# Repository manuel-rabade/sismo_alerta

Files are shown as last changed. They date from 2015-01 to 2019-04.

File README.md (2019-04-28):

Sismo Alerta
============

Receptor libre de la señal pública del [Sistema de Alerta Sísmica
Mexicano](http://www.cires.org.mx/sasmex_es.php).

Sismo Alerta emite un fuerte sonido y parpadea sus leds en caso de
recibir la alerta sísmica. Incluye batería de respaldo para no depender
de la energía de la red eléctrica.

Funcionamiento
--------------

Sismo Alerta es posible gracias a la señal pública del Sistema de Alerta
Sísmica Mexicano operado por el [Centro de Instrumentación y Registro
Sísmico](http://www.cires.org.mx/).

La señal del Sistema de Alerta Sísmica Mexicano es de tipo
[VHF](http://en.wikipedia.org/wiki/Very_high_frequency) en los canales
de [Weather Radio](http://en.wikipedia.org/wiki/Weather_radio) y utiliza
una versión modificiada del [protocolo
SAME](http://en.wikipedia.org/wiki/Specific_Area_Message_Encoding) para
transmitir alertas sobre distintos riesgos.

Sismo Alerta sintoniza y decodifica esta señal gracias al chip
[Si4707](http://www.silabs.com/products/audio/fm-am-receiver/pages/si4707.aspx)
que junto a una placa [Arduino](http://arduino.cc) dispara la alerta
sísmica de acuerdo al mensaje recibido.

Advertencia
-----------

Construye, utiliza y comparte Sismo Alerta bajo tu propio riesgo.

Sismo Alerta un proyecto experimental ejecutado por medio de [Ingeniería
inversa](https://es.wikipedia.org/wiki/Ingenier%C3%ADa_inversa) del
Sistema de Alerta Sísmica Mexicanos, además no cuenta con ninguna
certificación o permiso del Centro de Instrumentación y Registro
Sísmico, Gobierno de la Ciudad de México o Gobierno Federal.

Prototipo
---------

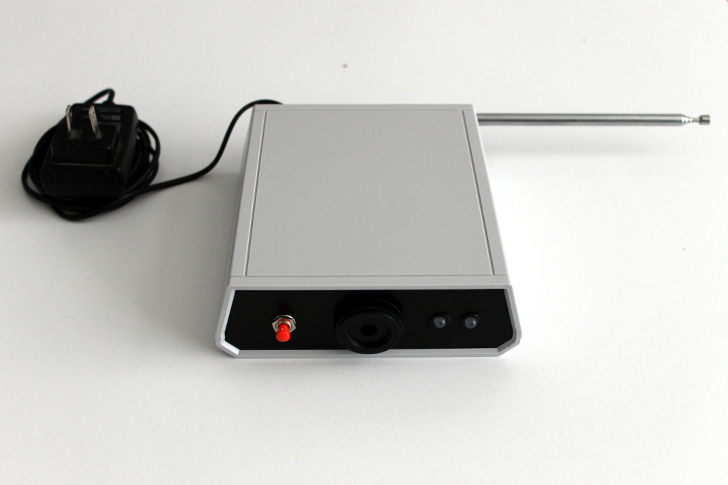
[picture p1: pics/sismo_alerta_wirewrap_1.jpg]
Wirewrap 1 (https://flic.kr/p/qupofe)


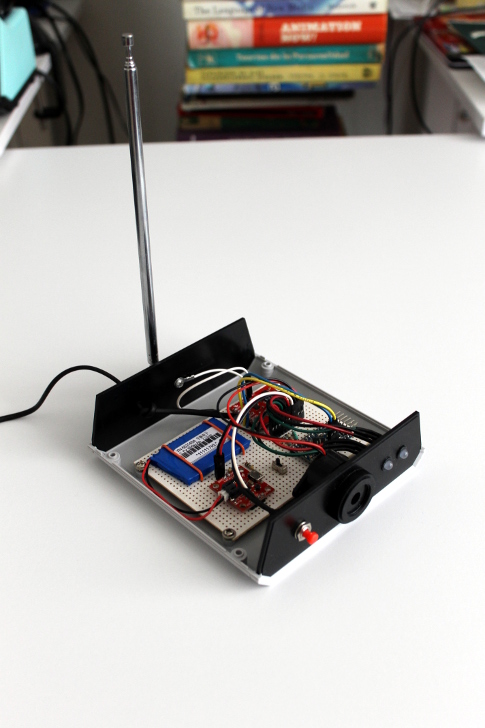
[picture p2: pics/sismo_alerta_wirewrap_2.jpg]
Wirewrap 2 (https://flic.kr/p/pPRnoG)


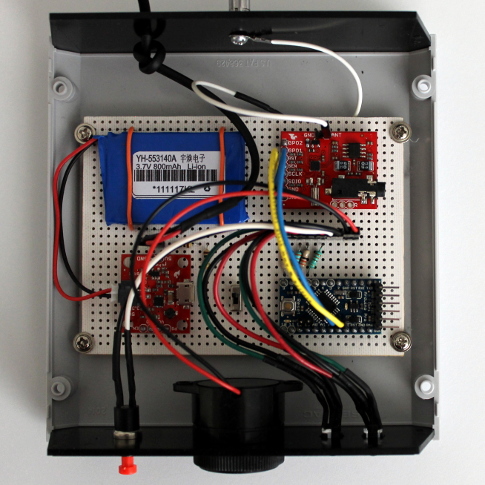
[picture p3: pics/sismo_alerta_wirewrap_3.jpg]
Wirewrap 3 (https://flic.kr/p/qwKxXX)


Kit
---

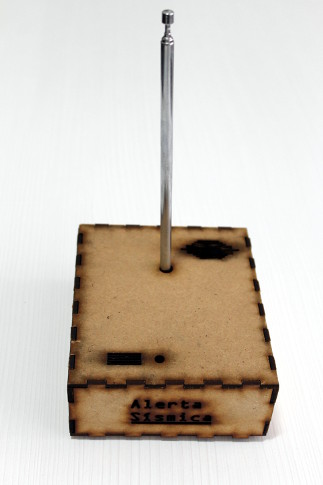
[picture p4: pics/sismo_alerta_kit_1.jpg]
Kit 1 (https://flic.kr/p/s8GZrR)


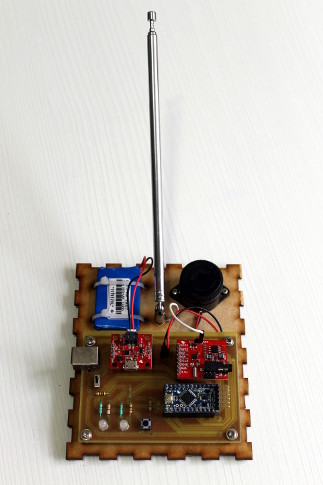
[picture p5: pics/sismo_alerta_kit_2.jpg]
Kit 2 (https://flic.kr/p/rvefon)


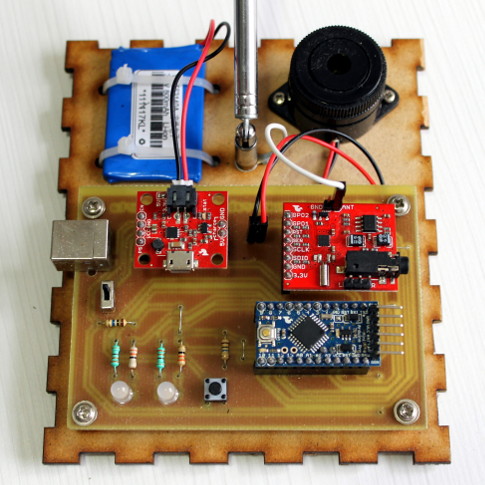
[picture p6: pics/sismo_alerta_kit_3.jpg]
Kit 3 (https://flic.kr/p/sarKxh)


Operación
---------

La interacción con el usuario es por medio de:

- Led bicolor (rojo y verde) marcado como _energía_.
- Led bicolor (rojo y verde) marcado como _señal_.
- Zumbador.
- Botón de usuario.

Al encender Sismo Alerta realiza una autoprueba que consiste en:

1. Encender ambos leds en color verde y activar el zumbador
2. Encender ambos leds en color rojo y desactivar el zumbador
3. Apagar ambos leds

Si después de la autoprueba se enciende el led de energía en color rojo
existe un problema interno.

Después de la autoprueba Sismo Alerta buscara el canal con mejor calidad
para monitorear la alerta sísmica. En caso de no encontrar un canal se
encenderá el led de señal en color rojo.

En caso de sintonizar un canal con éxito el led de señal encenderá
intermitentemente en color verde. Cuando Sismo Alerta reciba la prueba
periódica del Sistema de Alerta Sísmica el led de señal dejara de
parpadear y quedara encendido en color verde. El mensaje de prueba se
transmite cada 3 horas a partir de las 2:45.

En caso de recibir un mensaje de alerta sísmica ambos leds encenderán
intermitentemente en color rojo y el zumbador se activara. La duración
de la alerta es de 60 segundos.

Para probar Sismo Alerta basta con presionar el botón de usuario durante
al menos 3 segundos y se activara la alerta sísmica durante 10 segundos.

En resumen, los leds indican:

Led|Color|Significado
---|-----|-----------
Energía y Señal|Intermitente Rojo|Alerta sísmica
Señal|Apagado|Sintonizando canal por primera vez
Señal|Intermitente Verde|Canal sintonizado, esperando prueba periódica
Señal|Verde|Canal sintonizado y prueba periódica vigente
Señal|Rojo|No se pudo sintonizar un canal
Energía|Apagado|Apagada, batería de respaldo agotada
Energía|Verde|Alimentada por la red eléctrica
Energía|Intermitente Verde|Alimentada por la batería de respaldo
Energía|Rojo|Problema interno de hardware

Hardware
--------

### Lista de partes

Cantidad | Descripción
-------- | -----------
1 | [Arduino Pro Mini 3.3 V @ 8 Mhz](http://arduino.cc/en/Main/ArduinoBoardProMini)
1 | [Power Cell: LiPo Charger/Booster](https://www.sparkfun.com/products/11231) **
1 | [Si4707 Weather Band Receiver Breakout](https://www.sparkfun.com/products/11129)
1 | Batería Li-Ion 3.7 V @ 800 mAh conector JST **
2 | Led Bicolor 5 mm rojo/verde catodo común
2 | Resistencia 33 Ω 1/4 W
2 | Resistencia 330 Ω 1/4 W
2 | Resistencia 10M Ω 1/4 W
1 | Antena monopolo
1 | Zumbador
1 | Botón pulsador normalmente abierto
1 | Swtich 1 polo 2 tiros 2 posiciones **
1 | Conector USB tipo B hembra
1 | Convertidor AC a DC 5 V @ 500 mA conector USB tipo B macho

** Versión con batería de respaldo

#### Antena monopolo

Por la frecuencia de la señal pública del Sistema de Alerta Sísmico
Mexicano es muy fácil construir o adaptar una antena que nos permita
sintonizarla, hay dos opciones:

1. Tramo de 45 cm de cable.
2. Un elemento de una _antena de conejo_.

#### Importante

- Configurar la Power Cell a 3.3 V (cortar jumper 5V y soldar 3.3V).
- Configurar Si4707 Breakout para usar una antena externa (cortar jumper
  HP y soldar EXT).

### Esquema de conexiones

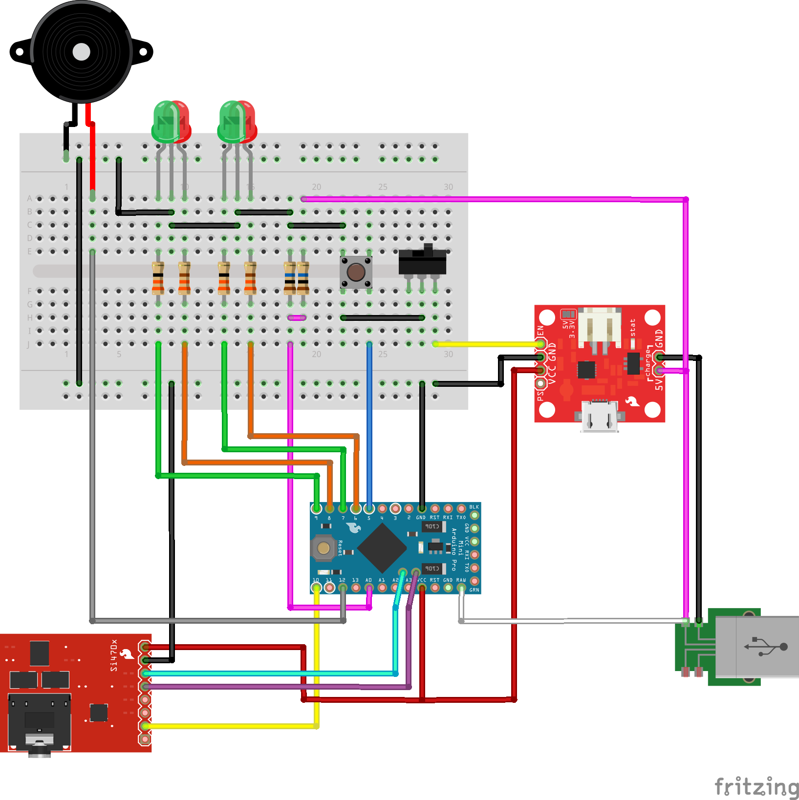
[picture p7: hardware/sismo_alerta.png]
Schematics


- La conexión blanca (abajo derecha) se debe hacer solo en caso de la
  versión sin batería de respaldo y Power Cell.

- No se muestra la antena que debe ir conectada al pin ANT de la Si4707
  Weather Band Receiver Breakout ni la batería que debe ir al conector
  JST de la Power Cell.

### PCB Kit

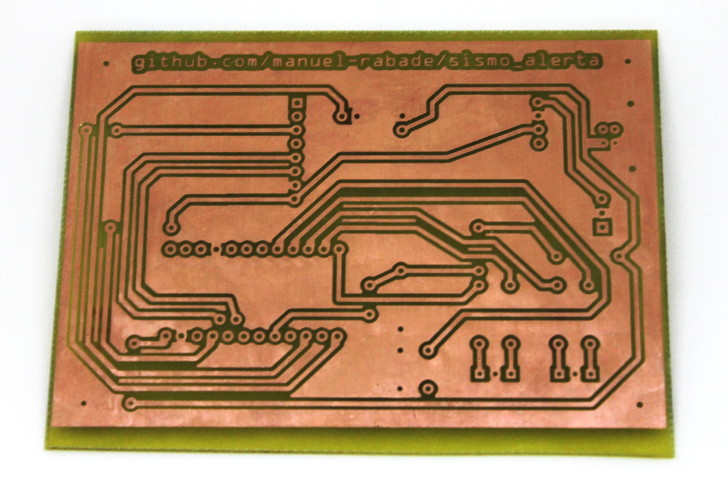
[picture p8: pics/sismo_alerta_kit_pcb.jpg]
Kit PCB (https://flic.kr/p/srSpnf)


- Pistas de cobre: [SVG](hardware/sismo_alerta_copper.svg), [2x2 SVG](hardware/sismo_alerta_copper_2x2.svg) o [2x2 PDF](hardware/sismo_alerta_copper_2x2.pdf)

- Máscara de soldadura: [SVG](hardware/sismo_alerta_mask.svg), [2x2 SVG](hardware/sismo_alerta_mask_2x2.svg) o [2x2 PDF](hardware/sismo_alerta_mask_2x2.pdf)

#### Componentes

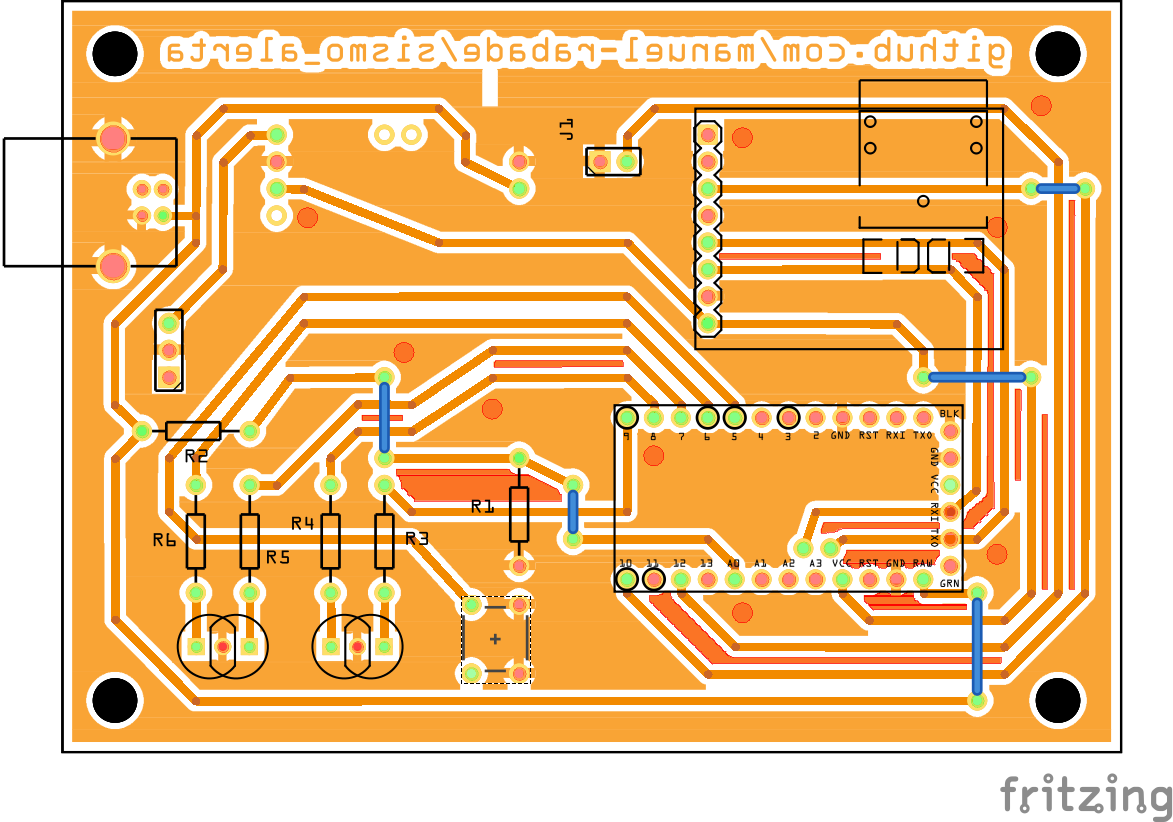
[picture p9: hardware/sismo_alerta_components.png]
Componentes PCB


Componente | Notas
---------- | -----
J1 | Puerto zumbador
R1, R2 | Resistencia 10M Ω 1/4 W
R3, R5 | Resistencia 33 Ω 1/4 W
R4, R6 | Resistencia 330 Ω 1/4 W
Jumper3 | (Esquina inferior derecha) Se debe omitir en la versión con batería de respaldo
S6 | Switch para apagar la versión con batería de respaldo en caso de almacenarla y así evitar se dañe la batería por perder toda la carga
Leds Bicolor | Comúnmente la terminal más larga corresponde al color rojo y esta va orientada hacía R4 o R6

### Gabinete Kit

- [SVG de la base para montaje](hardware/sismo_alerta_base.svg)
- Pendiente diseño del gabinete MDF

Firmware
--------

Para Arduino IDE 1.8.9 y requiere las siguientes bibliotecas:

- [Si4707 Weather Band Radio Receiver Library](https://github.com/manuel-rabade/Arduino-Si4707-Library)
- [TimerOne Library](https://github.com/PaulStoffregen/TimerOne)

La estructura de [SismoAlerta.ino](firmware/SismoAlerta/SismoAlerta.ino)
es:

- Una maquina de estados en el ciclo infinito del sketch encargada
  escaneo de canales y monitoreo de mensajes.
- Una interrupción periódica que monitorea el botón de usuario,
  actualiza los leds del dispositivo y activa el zumbador.

Los parámetros de operación del firmware se puede configurar en
[SismoAlerta.h](firmware/SismoAlerta/SismoAlerta.h).

En el puerto serial se registran los eventos de Sismo Alerta, por
ejemplo:

```
SETUP
SELFTEST
BEGIN
SCAN_START
SCAN_AVG,162400,9,0.00,0.00
SCAN_AVG,162425,9,0.00,0.00
SCAN_AVG,162450,9,0.00,0.00
SCAN_AVG,162475,9,0.00,0.00
SCAN_AVG,162500,9,2.00,7.56
SCAN_AVG,162525,9,0.00,0.00
SCAN_AVG,162550,9,5.00,8.78
SCAN_OK,162550
SNR_RSSI_AVG,162550,240,3.84,8.65
SNR_RSSI_AVG,162550,240,2.58,7.75
SNR_RSSI_AVG,162550,240,1.50,5.92
SAME_PRE_DET
SAME_HDR_DET
SAME_HDR_RDY,1
SAME_PRE_DET
SAME_HDR_DET
SAME_HDR_RDY,2
SAME_PRE_DET
SAME_HDR_DET
SAME_HDR_RDY,3
SAME,-CIV-RWT-000000+0300-1311431-XGDF/001-..,.
SAME_RWT
SAME_EOM_DET
SAME_PRE_DET
SAME_EOM_DET
SAME_PRE_DET
SAME_EOM_DET
SAME_PRE_DET
SAME_EOM_DET
SNR_RSSI_AVG,162550,240,1.97,6.38
SNR_RSSI_AVG,162550,240,2.72,8.13
```

Monitor
-------

Esta versión del Hardware utiliza un [Arduino
Yún](http://arduino.cc/en/Main/ArduinoBoardYun) para monitorear la
operación de Sismo Alerta.

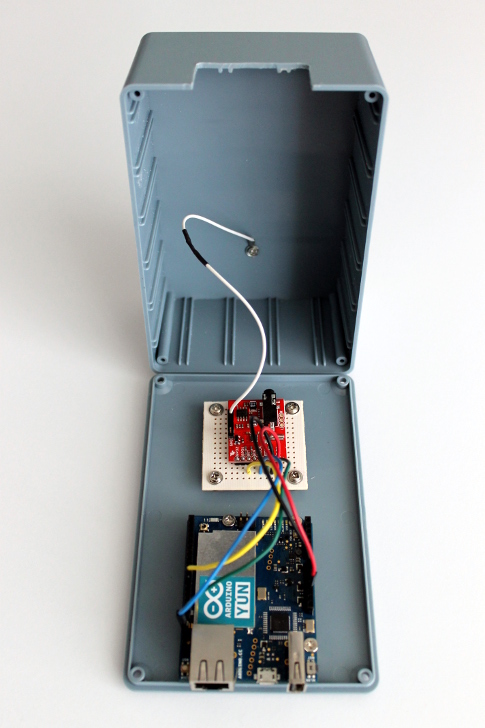
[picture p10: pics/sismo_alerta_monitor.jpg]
Monitor (https://flic.kr/p/qJyAiN)


#### Importante

Para que funcionen correctamente las opciones de la versión monitor se
debe descomentar la linea `reset-mcu` en `/etc/rc.local` del Linux
empotrado en el Arduino Yún. El objetivo es habilitar el reinicio del
microcontrolador después de terminar el arranque del Linux empotrado.

### Bitácora

Esta opción del Firmware guarda en archivos de texto cada evento de
Sismo Alerta.

El script [sismo_alerta_logger](software/logger/sismo_alerta_logger)
recibe los eventos de Sismo Alerta por medio de la consola virtual y los
guarda en carpetas y archivos de texto de acuerdo al año y día en que fueron
generados.

Para implementar la bitácora se debe:

1. Insertar una memoria SD previamente particionada y formateada en el
Arduino Yún. La memoria SD debe automontarse en `/mnt/sda1/` en el Linux
empotrado.

2. En el Linux empotrado del Arduino Yún se debe crear el directorio
`/mnt/sda/log` donde se guardaran las bitácoras de operación y copiar el
script [sismo_alerta_logger](software/logger/sismo_alerta_logger) en
`/root`.

3. En [SismoAlerta.h](firmware/SismoAlerta/SismoAlerta.h) activar la
opción `YUN_LOGGER`.

Un fragmento de bitácora del archivo `2015/0223.txt` seria:

```
[2015-02-23 13:38:00] SETUP
[2015-02-23 13:38:00] SELFTEST
[2015-02-23 13:39:02] BEGIN
[2015-02-23 13:39:03] SCAN_START
[2015-02-23 13:39:29] SCAN_AVG,162400,9,0.00,0.00
[2015-02-23 13:39:29] SCAN_AVG,162425,9,0.00,0.00
[2015-02-23 13:39:29] SCAN_AVG,162450,9,2.44,14.78
[2015-02-23 13:39:29] SCAN_AVG,162475,9,0.00,0.00
[2015-02-23 13:39:30] SCAN_AVG,162500,9,2.11,10.89
[2015-02-23 13:39:30] SCAN_AVG,162525,9,0.00,0.00
[2015-02-23 13:39:30] SCAN_AVG,162550,9,0.78,11.22
[2015-02-23 13:39:30] SCAN_OK,162450
[2015-02-23 13:59:33] SNR_RSSI_AVG,162450,240,2.49,16.12
[2015-02-23 14:19:35] SNR_RSSI_AVG,162450,240,1.38,15.40
[2015-02-23 14:39:37] SNR_RSSI_AVG,162450,240,1.23,15.21
[2015-02-23 14:45:02] SAME_PRE_DET
[2015-02-23 14:45:02] SAME_HDR_DET
[2015-02-23 14:45:03] SAME_HDR_RDY,1
[2015-02-23 14:45:05] SAME_PRE_DET
[2015-02-23 14:45:05] SAME_HDR_DET
[2015-02-23 14:45:06] SAME_HDR_RDY,2
[2015-02-23 14:45:07] SAME_PRE_DET
[2015-02-23 14:45:08] SAME_HDR_DET
[2015-02-23 14:45:08] SAME_HDR_RDY,3
[2015-02-23 14:45:09] SAME,-CIV-RWT-000000+0300-1311432-XGDF/003-D&@...
[2015-02-23 14:45:09] SAME_RWT
[2015-02-23 14:45:09] SAME_EOM_DET
[2015-02-23 14:45:10] SAME_PRE_DET
[2015-02-23 14:45:10] SAME_EOM_DET
[2015-02-23 14:45:12] SAME_PRE_DET
[2015-02-23 14:45:12] SAME_EOM_DET
[2015-02-23 14:45:14] SAME_PRE_DET
[2015-02-23 14:45:14] SAME_EOM_DET
[2015-02-23 14:59:39] SNR_RSSI_AVG,162450,240,2.14,10.37
[2015-02-23 15:19:41] SNR_RSSI_AVG,162450,240,1.82,11.26
[2015-02-23 15:39:43] SNR_RSSI_AVG,162450,240,2.27,11.83
```

### Repetidor Twitter

Esta opción del Firmware envía a un script web cada mensaje SAME
recibido. **El objetivo de esta opción no es transmitir la alerta
sísmica al público en general.**

El script [arduino.php](software/twitter/arduino.php) recibe los
mensajes SAME, los guarda en archivos de texto y los publica en Twitter
como [@SismoAlertaMX](https://twitter.com/sismoalertamx).

Para implementar el repetidor en twitter se debe:

1. Configurar en [config.php](software/twitter/config.php.sample) los
parámetros para guardar y consultar los mensajes SAME además de las
llaves secretas de Sismo Alerta y Twitter.

2. En [SismoAlerta.h](firmware/SismoAlerta/SismoAlerta.h) activar la
opción `YUN_TWITTER`.

3. En `yun_twitter.h` se debe configurar la URL del web service de Sismo
Alerta con su llave secreta (ver
[yun_twitter.h.example](firmware/SismoAlerta/yun_twitter.h.example)).

Autor
-----

Manuel Rábade <[manuel@rabade.net](mailto:manuel@rabade.net)>

Licencia
--------

Esta obra está bajo una [licencia de Creative Commons
Reconocimiento-CompartirIgual 4.0
Internacional](http://creativecommons.org/licenses/by-sa/4.0/).

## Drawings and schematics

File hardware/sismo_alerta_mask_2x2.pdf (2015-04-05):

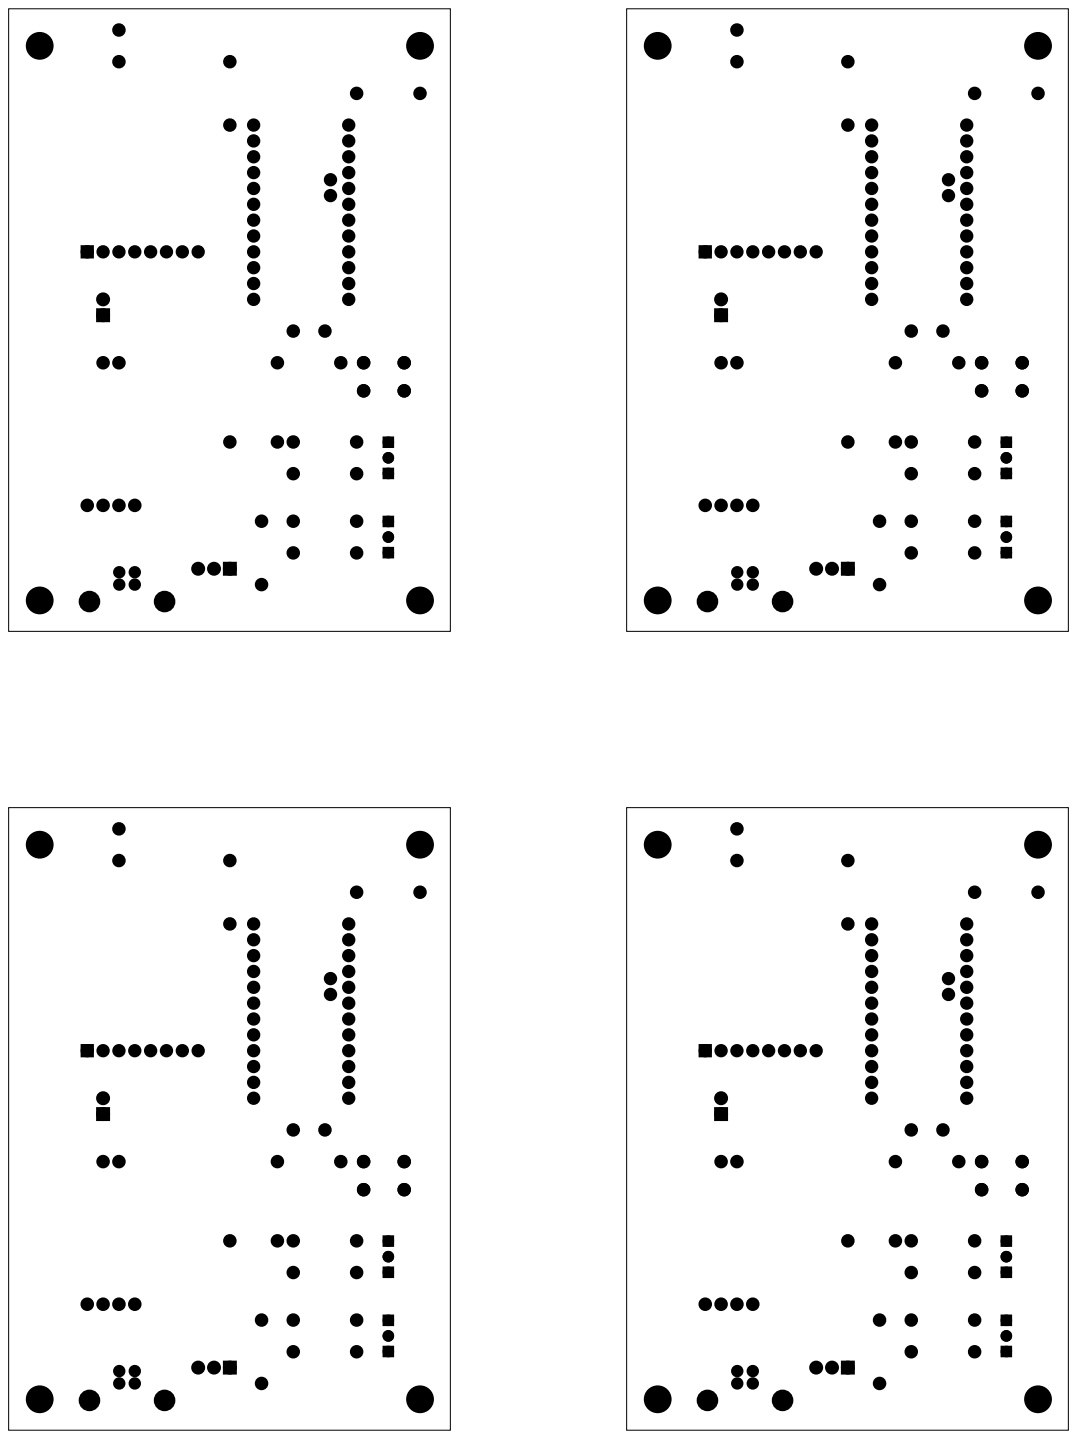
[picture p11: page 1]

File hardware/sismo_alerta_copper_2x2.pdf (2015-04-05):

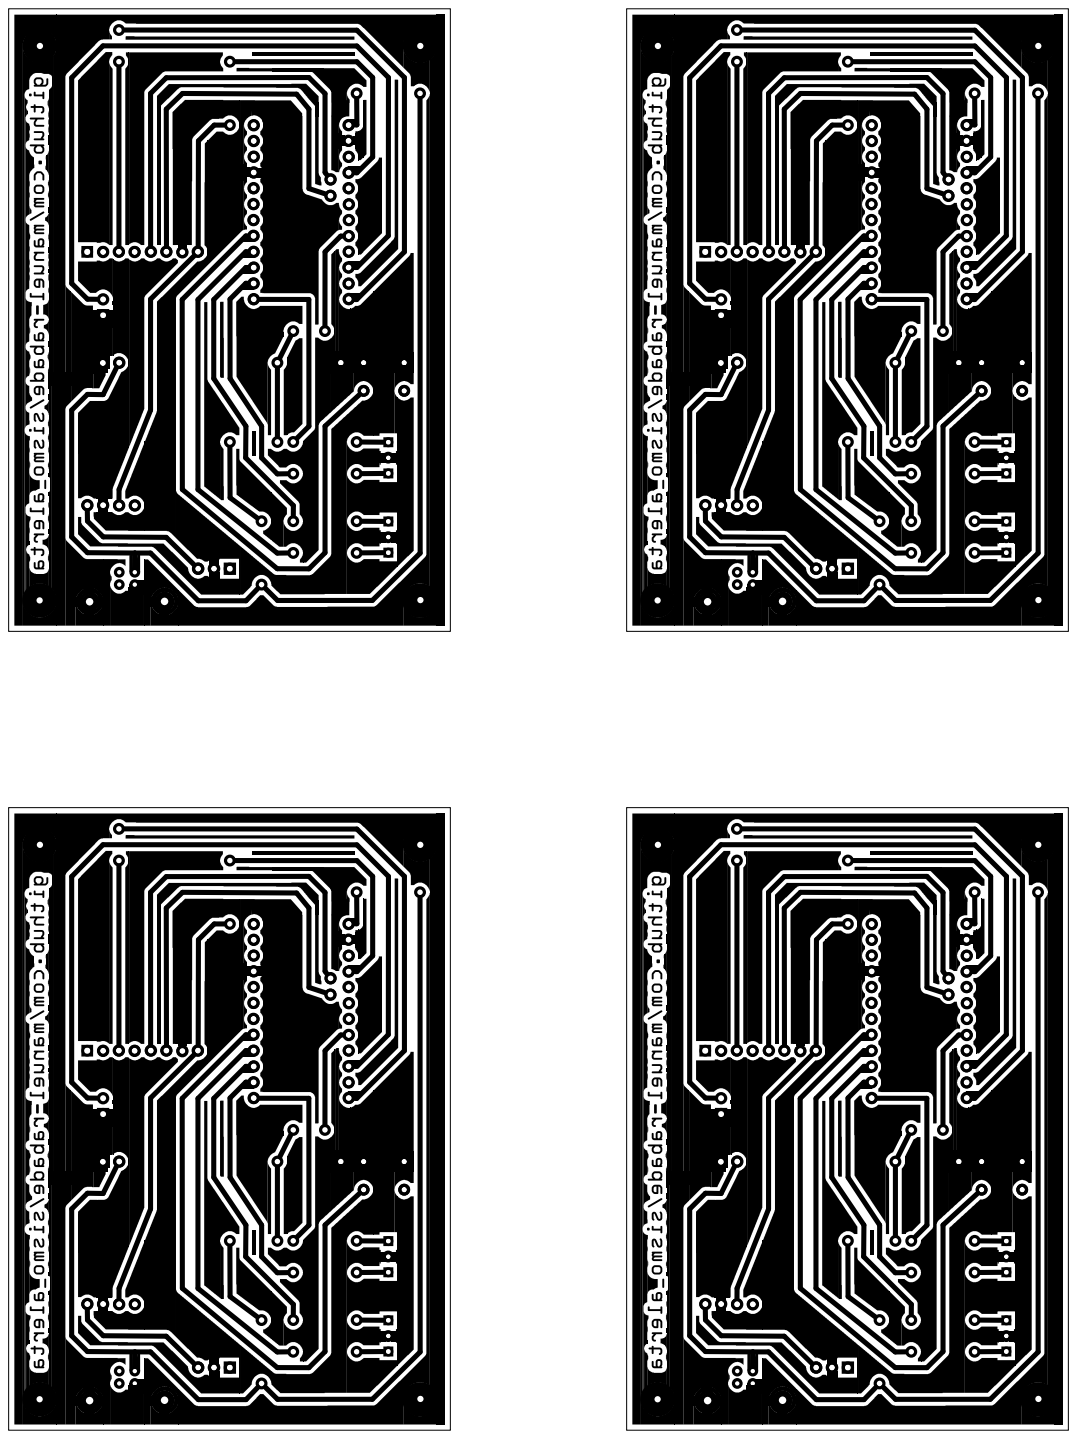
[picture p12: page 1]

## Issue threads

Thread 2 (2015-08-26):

Cambiar el voltaje del sistema de 3.3V a 5V

manuel-rabade, 2015-08-26:
Algunas Si4707 Weather Band Receiver Breakout (https://www.sparkfun.com/products/11129) no pueden establecer comunicación con el Arduino Pro Mini. Se necesita:

- Configurar Power Cell a 5V
- Agregar un regulador de voltaje de 3.3V para alimentar la Si4707 Breakout
- Ajustar conexiones de alimentación USB - PowerCell - Arduino Pro Mini - Si4707 Breakout
- Ajustar detección de energía externa en el firmware

La razón es que la Si47407 Breakout requiere alimentación de 3.3V pero esta diseñada para comunicarse a 5V (tienen un divisor de voltaje en SCLK y SDIO, ver https://cdn.sparkfun.com/datasheets/Wireless/General/SparkFun_Si4707_Breakout_v11.pdf).

Una solución temporal a este problema es eliminar los divisores de voltaje en SCLK y SDIO de la Si4707 Breakout (Quitar R3, R4, R5 y R6 y soldar jumpers en R3 y R4).

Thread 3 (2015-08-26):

Migrar esquemático y PCB de Fritzing

manuel-rabade, 2015-08-26:
- ¿El nuevo PCB debe ser de una cara (más practico para el DIY) o dos caras (apto para PCB Fab)?
- ¿Qué software de EDA es mejor que Fritzing? ¿Kicad? ¿Una solución en la nube como la de Altium o Upverter? Pros y contras.

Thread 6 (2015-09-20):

Mensaje en S.A.M.E.

sabas1080, 2015-09-20:
Hola, excelente trabajo
¿tendrás entre tus curiosidades uno(s) mensaje(s) completo(s) de SAME que me puedas pasar?

-CIV-RWT-000000+0300-1311432-XGDF/003-D&@...

saludos y gracias

manuel-rabade, 2015-11-16:
Hola,

Antes que nada muchas gracias por las felicitaciones y de verdad una disculpa por la demora.

Te comparto por acá ftp.rabade.net/tmp/sismo_alerta_logs-20150127-20150825.tar.gz los registros de operación del 26 de Enero al 28 de Agosto de la versión monitor de Sismo Alerta. En ellos puedes ver los mensajes SAME en crudo además de otras cosas como los reportes de calidad de recepción.

También por otra parte puedes dar click en los enlaces que acompañan a las publicaciones de https://twitter.com/sismoalertamx para ver el mensaje SAME en texto plano.

Saludos!

Closed 2015-11-16.

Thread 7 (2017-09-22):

¿Aún se encuentra activo el proyecto?

dsalcedo, 2017-09-22:

pixelead0, 2017-09-22:
Hola @dsalcedo al parecer el proyecto es funcional, al menos que sugieras alguna mejora.

manuel-rabade, 2017-09-23:
Mi última contribución al repo fue hace 2 años así que activo no lo llamaría. Por otra parte el proyecto sigue siendo vigente mientras se transmita la señal de la alerta sísmica en la banda de Weather Radio (NWR) mediante el protocolo SAME.

Closed 2017-09-23.

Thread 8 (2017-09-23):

Un componente clave enlistado ya no está a la venta

germanvaleroelizondo, 2017-09-23:
De acuerdo a la liga del componente Si4707 Weather Band Receiver Breakout,
que enlaza hacia la página https://www.sparkfun.com/products/retired/11129

SparkFun Weather Band Receiver Breakout - Si4707
Retired WRL-11129 RoHS Open Source Hardware
Note: Retired Product
This product has been retired from our catalog and is no longer for sale. This page is made available for those looking for datasheets and the simply curious.

compermisos, 2017-09-23:
El componente en cuestion es de fuente abierta y se encuentra disponible sus especificaciones en https://github.com/sparkfun/Si4707_Breakout

manuel-rabade, 2017-09-23:
Hola @germanvaleroelizondo, efectivamente las Breakouts del Si4707 ya no están a la venta.

Se puede volver a fabricar con el diseño de SparkFun como comenta @compermisos o actualizar el proyecto.

Forks y pull request son bienvenidas :smiley:

EsaMed, 2017-10-05:
Hola, de qué manera se podría actualizar el proyecto? Existe actualmente un breakout para otro integrado que haga la decodificación SAME? Estuve investigando un poco y parece ser que no. Espero me puedas ayudar. Saludos

rogeliomonter, 2018-03-07:
Encontré un componente similar (o al menos eso me parece) de venta en [aliexpress](https://es.aliexpress.com/store/product/SI4736-C40-GM-IC-RX-AM-FM-WB-RADIO-20UQFN-SI4736-C40-GM-4736-SI4736-I4736/1294792_32246128445.html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,searchweb201602_2_10152_10151_10065_10344_10068_10342_10343_10340_10341_10084_10083_10618_10307_5711211_10313_10059_10534_100031_10103_10627_10626_10624_10623_10622_10621_10620_5722413_5711313,searchweb201603_37,ppcSwitch_5&algo_expid=b87c8016-d919-4793-83b3-e1b46a846d62-1&algo_pvid=b87c8016-d919-4793-83b3-e1b46a846d62&transAbTest=ae803_3&priceBeautifyAB=0)
y su hoja de especificaciones https://www.silabs.com/documents/public/data-sheets/Si4736-37-38-39-C40.pdf

manuel-rabade, 2018-03-08:
Hola,

@EsaMed: hasta donde yo conozco no existe otro integrado con las características del Si4707
@rogeliomonter: Es un receptor de FM el que mencionas, el problema no es la disponibilidad del integrado si no del breakout.

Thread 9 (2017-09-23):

El modulo para el control de la bateria no se encuentra en venta

compermisos, 2017-09-23:
si bien los esquematicos se encuentran disponibles tal vez sea el momento de cambiarlo, esta pudiera ser una opcion https://www.sparkfun.com/products/13777

manuel-rabade, 2017-09-23:
Forks y pull request son bienvenidos :smiley:

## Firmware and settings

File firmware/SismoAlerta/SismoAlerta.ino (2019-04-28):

/*
  Copyright 2015 Manuel Rodrigo Rábade García <manuel@rabade.net>

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
  You should have received a copy of the GNU General Public License
  along with this program.  If not, see <http://www.gnu.org/licenses/>.
*/

#include "Wire.h"
#include <TimerOne.h>
#include <Si4707.h>
#include "SismoAlerta.h"
#if (YUN_LOGGER || YUN_TWITTER)
#include <Bridge.h>
#include <Console.h>
#if YUN_LOGGER
#include <Process.h>
#endif
#if YUN_TWITTER
#include <HttpClient.h>
#include "yun_twitter.h"
#endif
#endif

/* variables y objetos globales
   ============================ */

// weather band radio
Si4707 wbr(SI4707_RESET, SI4707_ENABLE);
const unsigned long wbr_channels[] = { WBR_CHANNELS };

// maquina de estados
enum fsm_states { SCAN, LISTEN } state = SCAN;

// escaneo
boolean scan_error_flag = 0;
byte tune_channel;

// monitoreo
boolean asq_prev_status;
byte same_prev_state, same_headers_count;
unsigned long tune_timer, same_timer, same_test_timer;

// servicio al usuario
volatile unsigned long user_test_timer = 0;
volatile unsigned long same_alert_timer = 0;
volatile unsigned int user_button_integrator = 0;
volatile boolean user_button_prev_state = HIGH;
volatile unsigned long last_user_button_push = 0;
volatile unsigned int ext_power_analog_avg;
volatile unsigned long last_update = 0;
volatile boolean update_state = LOW;

// monitoreo calidad de señal
#if SNR_RSSI_LOG
float snr_avg, rssi_avg;
unsigned long snr_rssi_sample_timer;
int snr_rssi_samples_count;
#endif

// modo arduino yún con bitácora
#if YUN_LOGGER
Process proc;
#endif

// modo arduino yún con retransmisor twitter
#if YUN_TWITTER
HttpClient http;
#endif

/* configuración
   ============= */

void setup() {
  // consola telnet o puerto serial
#if (YUN_LOGGER || YUN_TWITTER)
  Bridge.begin();
  LOG.begin();
#if YUN_LOGGER
  // proceso logger (nc localhost 6571 | ...)
  proc.runShellCommandAsynchronously("/root/sismo_alerta_logger");
  while (!LOG);
#endif
#else
  LOG.begin(9600);
  LOG.println();
#endif

  // entrada/salida
  LOG.println(F("SETUP"));
  pinMode(BUZZER, OUTPUT);
  pinMode(POWER_LED_RED, OUTPUT);
  pinMode(POWER_LED_GREEN, OUTPUT);
  pinMode(SIGNAL_LED_RED, OUTPUT);
  pinMode(SIGNAL_LED_GREEN, OUTPUT);
  pinMode(USER_BUTTON, INPUT_PULLUP);

  // autoprueba
  LOG.println(F("SELFTEST"));
  digitalWrite(POWER_LED_GREEN, HIGH);
  digitalWrite(SIGNAL_LED_GREEN, HIGH);
  digitalWrite(POWER_LED_RED, LOW);
  digitalWrite(SIGNAL_LED_RED, LOW);
  digitalWrite(BUZZER, HIGH);
  delay(SELFTEST_DELAY);
  digitalWrite(POWER_LED_GREEN, LOW);
  digitalWrite(SIGNAL_LED_GREEN, LOW);
  digitalWrite(POWER_LED_RED, HIGH);
  digitalWrite(SIGNAL_LED_RED, HIGH);
  digitalWrite(BUZZER, LOW);
  delay(SELFTEST_DELAY);
  digitalWrite(POWER_LED_RED, LOW);
  digitalWrite(SIGNAL_LED_RED, LOW);

  // si4707
  LOG.println(F("BEGIN"));
  if (wbr.begin()) {
    // interrupción de servicio al usuario
    ext_power_analog_avg = analogRead(EXT_POWER);
    Timer1.initialize(SERVICE_USER_MICROSEC);
    Timer1.attachInterrupt(service_user);
    // configuración si4707
    wbr.setMuteVolume(1);
    wbr.setSNR(TUNE_MIN_SNR);
    wbr.setRSSI(TUNE_MIN_RSSI);
  } else {
    // error si4707
    digitalWrite(POWER_LED_RED, HIGH);
    digitalWrite(POWER_LED_GREEN, LOW);
    digitalWrite(SIGNAL_LED_RED, LOW);
    digitalWrite(SIGNAL_LED_GREEN, LOW);
    LOG.println(F("ERROR"));
    while (1);
  }
}

/* maquina de estados
   ================== */

void loop() {
  switch (state) {
  case SCAN:
    scan();
    break;
  case LISTEN:
    listen();
    break;
  }
}

/* escaneo
   ======= */

void scan() {
  LOG.println(F("SCAN_START"));

  // promedios de rssi y snr
  float scan_rssi_avg[WBR_CHANNELS_SIZE] = { 0 };
  float scan_snr_avg[WBR_CHANNELS_SIZE] = { 0 };

  // escaneo
  for (byte t = 0; t < SCAN_TIMES; t++) {
    for (byte c = 0; c < WBR_CHANNELS_SIZE; c++) {
      wbr.setWBFrequency(wbr_channels[c]);
      for (byte s = 0; s < SCAN_SAMPLES; s++) {
        delay(SCAN_SAMPLE_DELAY);
        // muestreo
        unsigned int rssi = wbr.getRSSI();
        unsigned int snr = wbr.getSNR();
        // promedio móvil acumulativo
        scan_rssi_avg[c] += (rssi - scan_rssi_avg[c]) / (3 * t + s + 1);
        scan_snr_avg[c] += (snr - scan_snr_avg[c]) / (3 * t + s + 1);
        // reporte muestra
#if SCAN_VERBOSE
        LOG.print(F("SCAN_SAMPLE,"));
        LOG.print(wbr_channels[c], DEC);
        LOG.print(F(","));
        LOG.print(3 * t + s, DEC);
        LOG.print(F(","));
        LOG.print(rssi, DEC);
        LOG.print(F(","));
        LOG.println(snr, DEC);
#endif
      }
    }
    delay(SCAN_DELAY);
  }

  // mejor canal
  byte best_channel = 0;
  float best_rssi = 0;
  float best_snr = 0;

  // reporte promedios y búsqueda del mejor canal
  for (byte c = 0; c < WBR_CHANNELS_SIZE; c++) {
    LOG.print(F("SCAN_AVG,"));
    LOG.print(wbr_channels[c], DEC);
    LOG.print(F(","));
    LOG.print(SCAN_TIMES * SCAN_SAMPLES, DEC);
    LOG.print(F(","));
    LOG.print(scan_rssi_avg[c], 2);
    LOG.print(F(","));
    LOG.println(scan_snr_avg[c], 2);
    if (scan_rssi_avg[c] >= best_rssi && scan_snr_avg[c] >= best_snr) {
      best_channel = c;
      best_rssi = scan_rssi_avg[c];
      best_snr = scan_snr_avg[c];
    }
  }

  // ¿se encontró un canal valido?
  if (best_rssi >= (float) TUNE_MIN_RSSI && best_snr >= (float) TUNE_MIN_SNR) {
    // sintonizar canal y pasar a estado monitoreo
    state = LISTEN;
    scan_error_flag = 0;
    tune_channel = best_channel;
    wbr.setWBFrequency(wbr_channels[tune_channel]);
    LOG.print(F("SCAN_OK,"));
    LOG.println(wbr_channels[best_channel], DEC);
    // reinicio monitoreo
    asq_prev_status = 0;
    same_prev_state = 0;
    same_headers_count = 0;
    tune_timer = millis();
    same_timer = 0;
    same_test_timer = 0;
    // reinicio monitoreo calidad de señal
#if SNR_RSSI_LOG
    snr_rssi_sample_timer = millis();
    rssi_avg = 0;
    snr_avg = 0;
    snr_rssi_samples_count = 0;
#endif
  } else {
    // repetir escaneo
    scan_error_flag = 1;
    LOG.println(F("SCAN_ERROR"));
    delay(SCAN_DELAY);
  }
}

/* monitoreo
   ========= */

void listen() {
  // ¿el canal es valido?
  if (wbr.getRSQ()) {
    tune_timer = millis();
  } else {
    if (millis() - tune_timer > TUNE_LOST_DELAY) {
      // reporte calidad de señal
#if SNR_RSSI_LOG
      LOG.print(F("SNR_RSSI_AVG,"));
      LOG.print(wbr_channels[tune_channel], DEC);
      LOG.print(F(","));
      LOG.print(snr_rssi_samples_count, DEC);
      LOG.print(F(","));
      LOG.print(rssi_avg, 2);
      LOG.print(F(","));
      LOG.println(snr_avg, 2);
#endif
      // pasar a estado escaneo
      state = SCAN;
      same_test_timer = 0;
      LOG.print(F("TUNE_LOST,"));
      LOG.println(wbr_channels[tune_channel], DEC);
      return;
    }
  }

  // monitoreo tono 1050 khz
  boolean asq_status = wbr.getASQ();
  if (asq_prev_status != asq_status) {
    if (asq_status) {
      same_reset();
      LOG.println(F("ASQ_ON"));
    } else {
      LOG.println(F("ASQ_OFF"));
    }
    asq_prev_status = asq_status;
    return;
  }

  // monitoreo mensajes same
  byte same_state = wbr.getSAMEState();
  if (same_prev_state != same_state) {
    switch (same_state) {
    case SAME_EOM_DET:
      // fin del mensaje
      LOG.println(F("SAME_EOM_DET"));
      // ¿se recibieron una o dos cabeceras?
      if (same_headers_count > 0) {
        same_message();
      } else {
        same_reset();
      }
      break;
    case SAME_PRE_DET:
      // preámbulo detectado
      same_timer = millis();
      LOG.println(F("SAME_PRE_DET"));
      break;
    case SAME_HDR_DET:
      // cabecera detectada
      same_timer = millis();
      LOG.println(F("SAME_HDR_DET"));
      break;
    case SAME_HDR_RDY:
      // cabecera lista
      same_timer = millis();
      same_headers_count++;
      LOG.print(F("SAME_HDR_RDY,"));
      LOG.println(same_headers_count);
      break;
    }
    // ¿se recibieron tres cabeceras?
    if (same_headers_count == 3) {
      same_message();
    }
    same_prev_state = same_state;
    return;
  }

  // timeout mensaje same
  if (same_timer && millis() - same_timer > SAME_TIMEOUT) {
    LOG.println(F("SAME_TIMEOUT"));
    // ¿se recibieron una o dos cabeceras?
    if (same_headers_count > 0) {
      same_message();
    } else {
      same_reset();
    }
  }

  // timeout prueba same
  if (same_test_timer && millis() - same_test_timer > SAME_TEST_TIMEOUT) {
    same_test_timer = 0;
    LOG.println(F("SAME_TEST_TIMEOUT"));
  }

  // monitoreo calidad de señal
#if SNR_RSSI_LOG
  if (millis() - snr_rssi_sample_timer > SNR_RSSI_SAMPLE_DELAY) {
    // muestreo
    unsigned int rssi = wbr.getRSSI();
    unsigned int snr = wbr.getSNR();
    // promedio móvil acumulativo
    rssi_avg += (rssi - rssi_avg) / (snr_rssi_samples_count + 1);
    snr_avg += (snr - snr_avg) / (snr_rssi_samples_count + 1);
    // reporte muestra
#if SNR_RSSI_VERBOSE
    LOG.print(F("SNR_RSSI_SAMPLE,"));
    LOG.print(wbr_channels[tune_channel], DEC);
    LOG.print(F(","));
    LOG.print(snr_rssi_samples_count, DEC);
    LOG.print(F(","));
    LOG.print(rssi, DEC);
    LOG.print(F(","));
    LOG.println(snr, DEC);
#endif
    // actualización timer y conteo
    snr_rssi_sample_timer = millis();
    snr_rssi_samples_count++;
  }
  if (snr_rssi_samples_count == SNR_RSSI_LOG_SAMPLES) {
    // reporte calidad de señal
    LOG.print(F("SNR_RSSI_AVG,"));
    LOG.print(wbr_channels[tune_channel], DEC);
    LOG.print(F(","));
    LOG.print(snr_rssi_samples_count, DEC);
    LOG.print(F(","));
    LOG.print(rssi_avg, 2);
    LOG.print(F(","));
    LOG.println(snr_avg, 2);
    // reinicio promedios y contador
    rssi_avg = 0;
    snr_avg = 0;
    snr_rssi_samples_count = 0;
  }
#endif
}

/* mensajes same
   ============= */

void same_message() {
  byte size = wbr.getSAMESize();
  // ¿mensaje vacío?
  if (size < 1) {
    LOG.println(F("SAME_EMPTY"));
    return;
  }

  // adquisición mensaje
  byte msg[size];
  wbr.getSAMEMessage(size, msg);
  same_reset();

  // reportamos mensaje
  LOG.print(F("SAME,"));
  for (byte i = 0; i < size; i++) {
    if (msg[i] > 31 && msg[i] < 127) {
      LOG.write(msg[i]);
    } else {
      LOG.print(F("."));
    }
  }
  LOG.println();

  // interpretación mensaje
  if (size >= 38) {
    if (msg[5] == 'E' &&
        msg[6] == 'Q' &&
        msg[7] == 'W') {
      // alerta sísmica
      same_alert_timer = millis();
      LOG.println(F("SAME_EQW"));
    } else if (msg[5] == 'R' &&
               msg[6] == 'W' &&
               msg[7] == 'T') {
      // prueba periódica
      same_test_timer = millis();
      LOG.println(F("SAME_RWT"));
    }
  }

  // publicación mensaje
#if YUN_TWITTER
  String url = WS_URL;
  url += "?secret=";
  url += WS_SECRET;
  url += "&same=";
  for (byte i = 0; i < size; i++) {
    url += (int) msg[i];
    url += ':';
  }
  http.getAsynchronously(url);
  LOG.print(F("URL,"));
  LOG.println(url);
#endif
}

void same_reset() {
  // reinicio buffer, timer y contador
  wbr.clearSAMEBuffer();
  same_timer = 0;
  same_headers_count = 0;
}

/* servicio al usuario
   =================== */

void service_user() {
  // integrador botón de usuario
  if (digitalRead(USER_BUTTON)) {
    if (user_button_integrator < USER_BUTTON_INT_MAX) {
      user_button_integrator++;
    }
  } else {
    if (user_button_integrator > 0) {
      user_button_integrator--;
    }
  }
  boolean user_button_state = user_button_prev_state;
  if (user_button_integrator == 0) {
    user_button_state = LOW;
  } else if (user_button_integrator >= USER_BUTTON_INT_MAX) {
    user_button_state = HIGH;
    user_button_integrator = USER_BUTTON_INT_MAX;
  }

  // monitoreo botón de usuario
  if (user_button_prev_state != user_button_state) {
    if (user_button_state == LOW) {
      user_test_timer = 0;
      last_user_button_push = millis();
    }
    user_button_prev_state = user_button_state;
  } else {
    if (user_button_state == LOW) {
      if (millis() - last_user_button_push > USER_BUTTON_TEST_DELAY) {
        user_test_timer = millis();
        last_user_button_push = 0;
      }
    }
  }

  // promedio móvil compensado del voltaje externo
  ext_power_analog_avg *= 1 - (float) EXT_POWER_A;
  ext_power_analog_avg += analogRead(EXT_POWER) * (float) EXT_POWER_A;

  // actualización
  if (millis() - last_update > UPDATE_DELAY) {
    update_state = !update_state;
    if (same_alert_timer || user_test_timer) {
      alert_user();
    } else {
      update_user();
    }
    last_update = millis();
  }
}

void alert_user() {
  // alerta usuario
  digitalWrite(SIGNAL_LED_RED, update_state);
  digitalWrite(SIGNAL_LED_GREEN, LOW);
  digitalWrite(POWER_LED_RED, !update_state);
  digitalWrite(POWER_LED_GREEN, LOW);
  digitalWrite(BUZZER, update_state);
  // alerta sísmica
  if (millis() - same_alert_timer > ALARM_TIME) {
    same_alert_timer = 0;
  }
  // prueba de usuario
  if (millis() - user_test_timer > TEST_TIME) {
    user_test_timer = 0;
  }
}

void update_user() {
  // buzzer apagado
  digitalWrite(BUZZER, LOW);

  // led señal
  if (state == SCAN) {
    // escaneo
    if (scan_error_flag) {
      // error
      digitalWrite(SIGNAL_LED_GREEN, LOW);
      digitalWrite(SIGNAL_LED_RED, HIGH);
    } else {
      // sintonizando por primera vez
      digitalWrite(SIGNAL_LED_GREEN, LOW);
      digitalWrite(SIGNAL_LED_RED, LOW);
    }
  } else {
    // monitoreo
    digitalWrite(SIGNAL_LED_RED, LOW);
    if (same_test_timer) {
      // prueba same vigente
      digitalWrite(SIGNAL_LED_GREEN, HIGH);
    } else {
      // no hay prueba same vigente
      digitalWrite(SIGNAL_LED_GREEN, update_state);
    }
  }

  // led energía
  volatile unsigned int milivolts = ext_power_analog_avg * (float) EXT_POWER_M;
  if (milivolts >= CHARGE_VOLTAGE) {
    // energía externa
    digitalWrite(POWER_LED_RED, LOW);
    digitalWrite(POWER_LED_GREEN, HIGH);
  } else {
    // batería
    digitalWrite(POWER_LED_RED, LOW);
    digitalWrite(POWER_LED_GREEN, !update_state);
  }
}

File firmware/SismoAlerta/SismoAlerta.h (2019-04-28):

/* entrada/salida
   --------------

   SI4707_RESET: pin reset si4707
   USER_BUTTON: pin botón usuario
   BUZZER: pin zumbador
   EXT_POWER: pin analógico voltaje externo
   POWER_LED_RED: pin led rojo energía
   POWER_LED_GREEN: pin led verde energía
   SIGNAL_LED_RED: pin led rojo señal
   SIGNAL_LED_GREEN: pin led verde señal */

#define SI4707_RESET 10
#define SI4707_ENABLE 11 // obsoleto
#define USER_BUTTON 5
#define BUZZER 12
#define EXT_POWER 0
#define POWER_LED_RED 6
#define POWER_LED_GREEN 7
#define SIGNAL_LED_RED 8
#define SIGNAL_LED_GREEN 9

/* parámetros de operación
   -----------------------

   SCAN_TIMES: numero de escaneos
   SCAN_DELAY: retardo entre escaneos (milisegundos)
   SCAN_SAMPLES: muestras por canal por escaneo
   SCAN_SAMPLE_DELAY: retardo para muestrear canal (milisegundos)
   SCAN_VERBOSE: informar cada muestra del escaneo (0 o 1)
   TUNE_MIN_RSSI: potencia mínima (db)
   TUNE_MIN_SNR: relación señal/ruido mínima (db)
   TUNE_LOST_DELAY: retardo para declarar un canal perdido (milisegundos)
   ALARM_TIME: duración alarma (milisegundos)
   TEST_TIME: duración prueba de alarma (milisegundos)
   SERVICE_USER_FREQ: frecuencia de actualización al usuario (hertz)
   USER_BUTTON_DEBOUNCE: retardo antirebote del botón de usuario (milisegundos)
   USER_BUTTON_TEST_DELAY: retardo para ejecutar prueba de usuario (milisegundos)
   CHARGE_VOLTAGE: voltaje mínimo para cargar la batería interna (milivolts)
   EXT_POWER_A: constante para el promedio móvil del voltaje externo (0 a 1)
   UPDATE_DELAY: retardo para actualizar al usuario (milisegundos)
   SELFTEST_DELAY: retardo autoprueba (milisegundos)
   SNR_RSSI_LOG: monitoreo calidad de señal (0 o 1)
   SNR_RSSI_LOG_SAMPLES: muestras de calidad de señal a promediar
   SNR_RSSI_SAMPLE_DELAY: retardo para muestrear la calidad de señal (milisegundos)
   SNR_RSSI_VERBOSE: informar cada muestra de calidad de señal (0 o 1) */

#define SCAN_TIMES 3
#define SCAN_DELAY 1000
#define SCAN_SAMPLES 3
#define SCAN_SAMPLE_DELAY 300
#define SCAN_VERBOSE 0
#define TUNE_MIN_RSSI 2
#define TUNE_MIN_SNR 5
#define TUNE_LOST_DELAY 300000 // 5 minutos
#define ALARM_TIME 60000 // 1 minuto
#define TEST_TIME 10000 // 10 segundos
#define SERVICE_USER_FREQ 20 // 50 milisegundos
#define USER_BUTTON_DEBOUNCE 100
#define USER_BUTTON_TEST_DELAY 3000 // 3 segundos
#define CHARGE_VOLTAGE 3750
#define EXT_POWER_A 0.70
#define UPDATE_DELAY 500
#define SELFTEST_DELAY 1000
#define SNR_RSSI_LOG 1
#define SNR_RSSI_LOG_SAMPLES 240 // 20 minutos
#define SNR_RSSI_SAMPLE_DELAY 5000 // 5 segundos
#define SNR_RSSI_VERBOSE 0

/* weather band radio
   ------------------

   WBR_CHANNELS: frecuencia de los canales de weather band radio (en khz)
   WBR_CHANNELS_SIZE: número de canales de weather band radio */

#define WBR_CHANNELS 162400,162425,162450,162475,162500,162525,162550
#define WBR_CHANNELS_SIZE 7

/* monitoreo
   ---------

   YUN_LOGGER: modo arduino yún con bitácora (0 o 1)
   YUN_TWITTER: modo arduino yún con retransmisor twitter (0 o 1) */

#define YUN_LOGGER 0
#define YUN_TWITTER 0

/* consola
   ------- */

#if (YUN_LOGGER || YUN_TWITTER)
#define LOG Console
#else
#define LOG Serial
#endif

/* constantes
   ---------- */

#define SAME_EOM_DET 0
#define SAME_PRE_DET 1
#define SAME_HDR_DET 2
#define SAME_HDR_RDY 3
#define SAME_TIMEOUT 6000
#define SAME_TEST_TIMEOUT 11400000 // 3 horas y 10 minutos
#define SERVICE_USER_MICROSEC (1000000 / SERVICE_USER_FREQ)
#define USER_BUTTON_INT_MAX ((USER_BUTTON_DEBOUNCE * SERVICE_USER_FREQ) / 1000)
#define EXT_POWER_M (3300 / 512)

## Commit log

2015-01-01 primera version hardware
    [sismo_alerta_diy.fzz]
2015-01-01 draft readme
    [sismo_alerta.fzz]
2015-01-07 borramos draft de sketch
2015-01-07 ajustamos parametros del sensor de carga de la bateria
2015-01-11 - mejoramos esaneo de canales - modo YUN_TWITTER para el retransmisor en twitter
2015-01-15 fotos verticales a 485 de ancho
2015-01-26 separamos configuracion del modo yun twitter en yun_twitter.h y subimos ejemplo. si recibimos menos de tres cabeceras sames las usamos antes de same_reset.
2015-01-27 opcion bitacora de la version monitor
2015-01-27 eliminamos boton de reset, documentamos led de señal apagado (sintonizando canal)
    [sismo_alerta.fzz]
2015-01-27 documentando led de energía apagado
2015-01-27 misc leds
2015-02-23 monitoreo calidad de la señal
2015-02-23 swtich para deshabilitar regulador de voltaje
    [sismo_alerta.fzz]
2015-02-23 sync ejemplos con firmware, mejoras bom, dependencias firmware
2015-02-23 fix png esquema de conexiones
2015-03-01 opcion sin bateria de respaldo
    [sismo_alerta.fzz]
2015-03-02 mejoramos opcion sin bateria de respaldo
    [sismo_alerta.fzz]
2015-04-05 diseño pcb
    [sismo_alerta.fzz]
2015-04-05 mascara para cobre
2015-04-05 mascara para soldermask
2015-08-26 pcb kit
2015-08-26 svg y pdf pcb
2015-08-26 fix svg y pdf pcb links
2019-04-28 sync w/Arduino Si4707 Library

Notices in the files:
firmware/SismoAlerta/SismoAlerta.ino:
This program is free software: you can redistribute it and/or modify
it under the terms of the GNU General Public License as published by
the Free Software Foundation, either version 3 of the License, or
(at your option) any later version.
